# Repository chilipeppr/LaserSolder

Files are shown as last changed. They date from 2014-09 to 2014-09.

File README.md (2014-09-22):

LaserSolder
===========

The laser solderer widget for ChiliPeppr that uses an Arduino to control a laser with an infrared heat sensor and a PID to ensure accurate soldering.

ChiliPeppr Widget
-----------
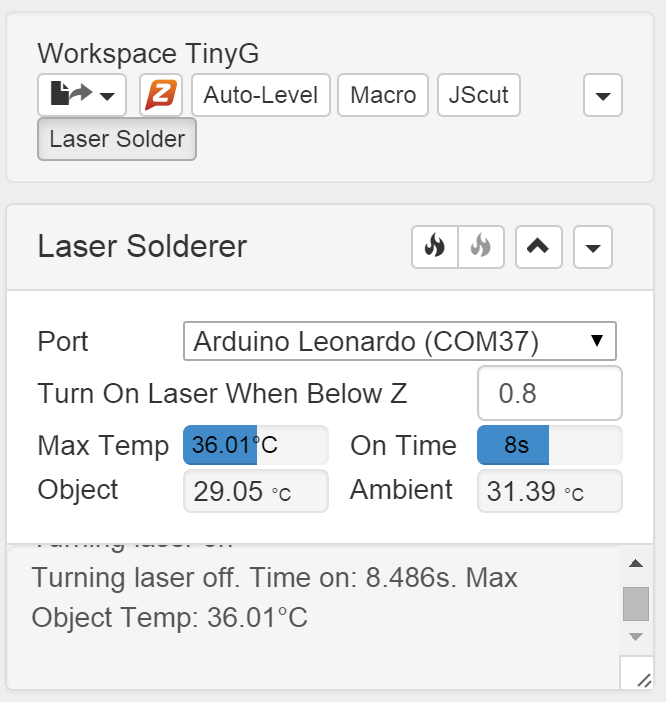
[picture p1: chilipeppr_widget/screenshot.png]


The widget lets you set at which Z height the laser will turn on. The laser is toggled from a normal Arduino. The command "laser-on" or "laser-off" is sent to the Arduino to toggle. You must also pick which port the Arduino is on. The Arduino also reports back every 500ms what the temperature of the Melexis infrared heat sensor readings are as a JSON string in the format {"a":27.54, "o":31.34} where "a" is the ambient temperature and "o" is the object's temperature in degrees Celsius. You can also toggle the laser manually.

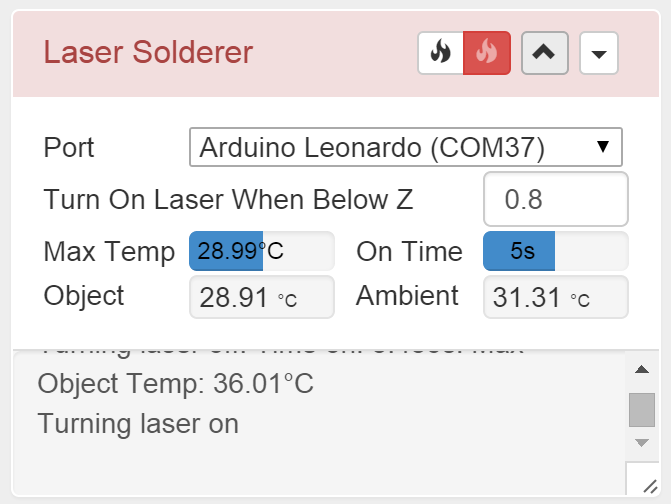
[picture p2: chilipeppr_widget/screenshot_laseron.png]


When the laser is on the widget goes red to indicate the state. You can always manually turn the laser off to override the auto-toggling based on the Z axis position.

Arduino Code
----------
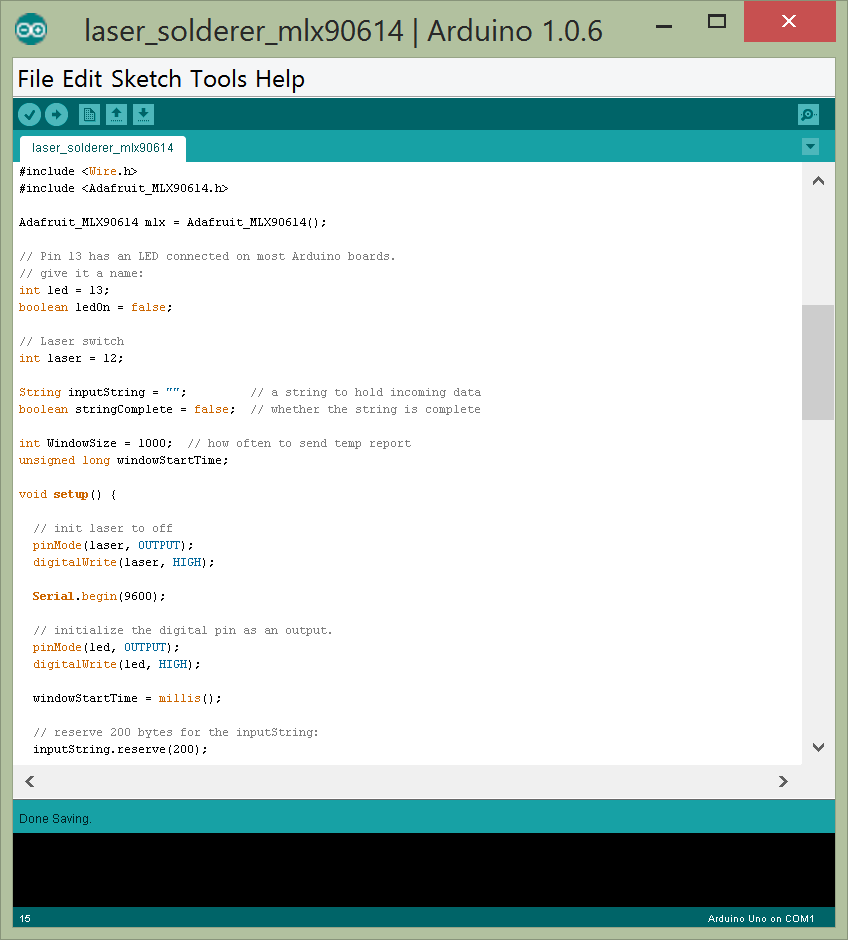
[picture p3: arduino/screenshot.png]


Just use a standard Arduino and upload the code contained in this repository. Modify as you like. You'll be running your Arduino on the same computer as your CNC machine so you can bind to both the serial port of your CNC controller like a TinyG as well as bind to your Arduino via its serial port.

The Arduino controls a laser by toggling PIN 12 on and off. You need
to connect a solid state relay, regular relay, or toggle a TTL signal
on a bench power supply. Or you can use something like a FlexMod P3
to toggle the laser on/off.

The laser used is a 3W 445nm Blue Diode laser in a standard 9mm casing
with a heatsink. You can find the laser at https://sites.google.com/site/dtrlpf/home/diodes/9mm-445nm

The Melexis MLX90614 is used for infrared temperature sensing. You
should get the 5 degree FOV version which is around $48. The link to this sensor is http://www.digikey.com/product-detail/en/MLX90614ESF-BCI-000-TU/MLX90614ESF-BCI-000-TU-ND/2666249

Eagle Schematics
----------
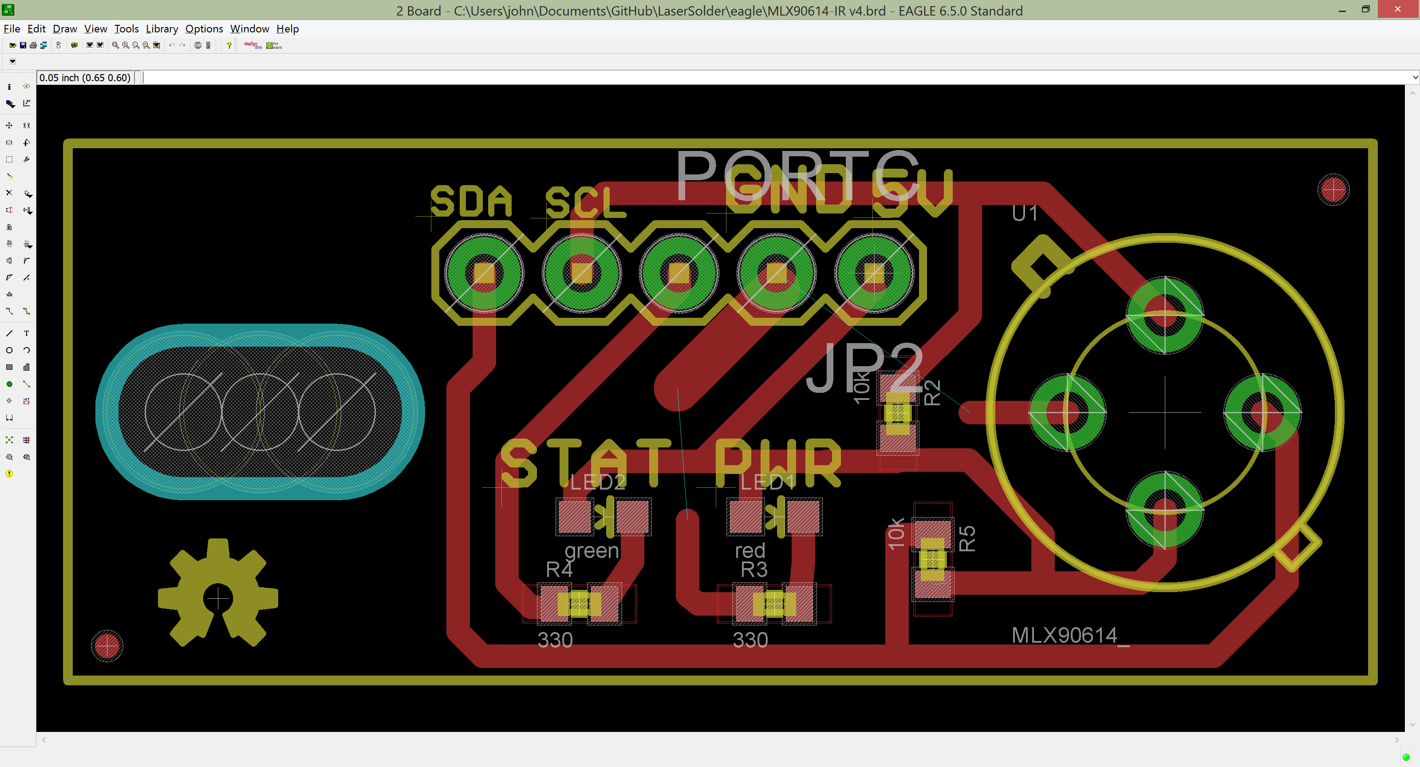
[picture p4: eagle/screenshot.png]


The Eagle design is in the eagle folder of this repository. It's simply a breakout board for the Melexis MLX90614 so you can connect it to your Arduino. It has two LEDs to indicate laser on/off status and power to the Melexis. There is a cutout on the board so you can bolt it to the design of the holder that is described below.

Freecad Design
----------
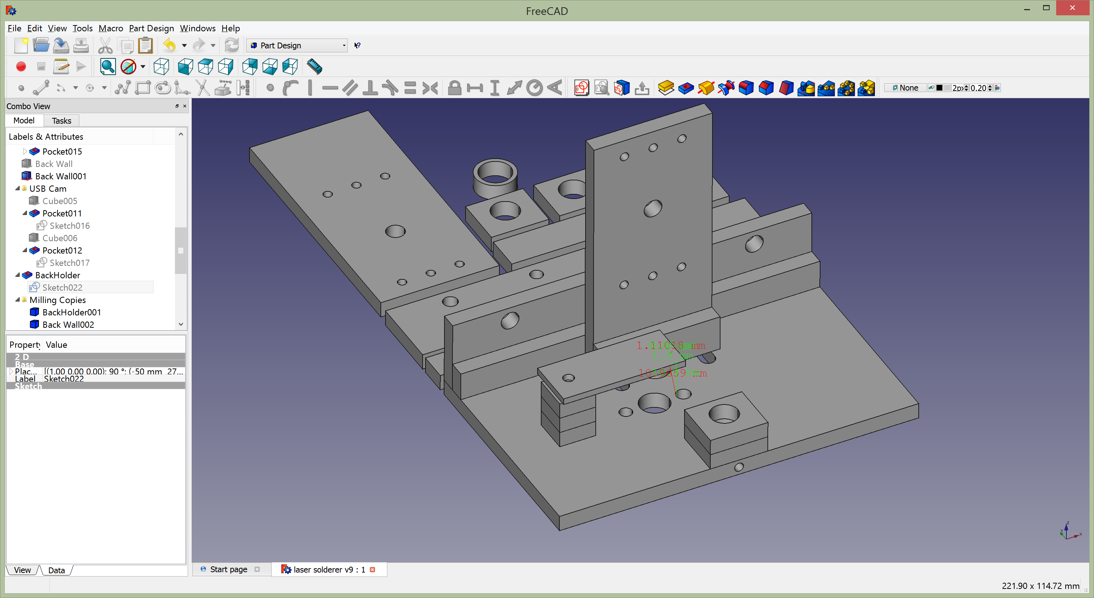
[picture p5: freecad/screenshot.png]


The design of the holder for the laser, Melexis MLX90614, the breakout board, and USB Microscope is in the freecad folder in this repo. Freecad is a great tool for basic CAD design. The CAD design was exported to DXF's and then brought into CamBam to generate the acrylic milling operations. The acrylic was then super glued or bolted together. Several M3 an M4 taps were created in the acrylic to enable bolting.

The back holder mounts to the standard Shapeoko mounts for a spindle so you can adjust the height of the laser holder on your Shapeoko.

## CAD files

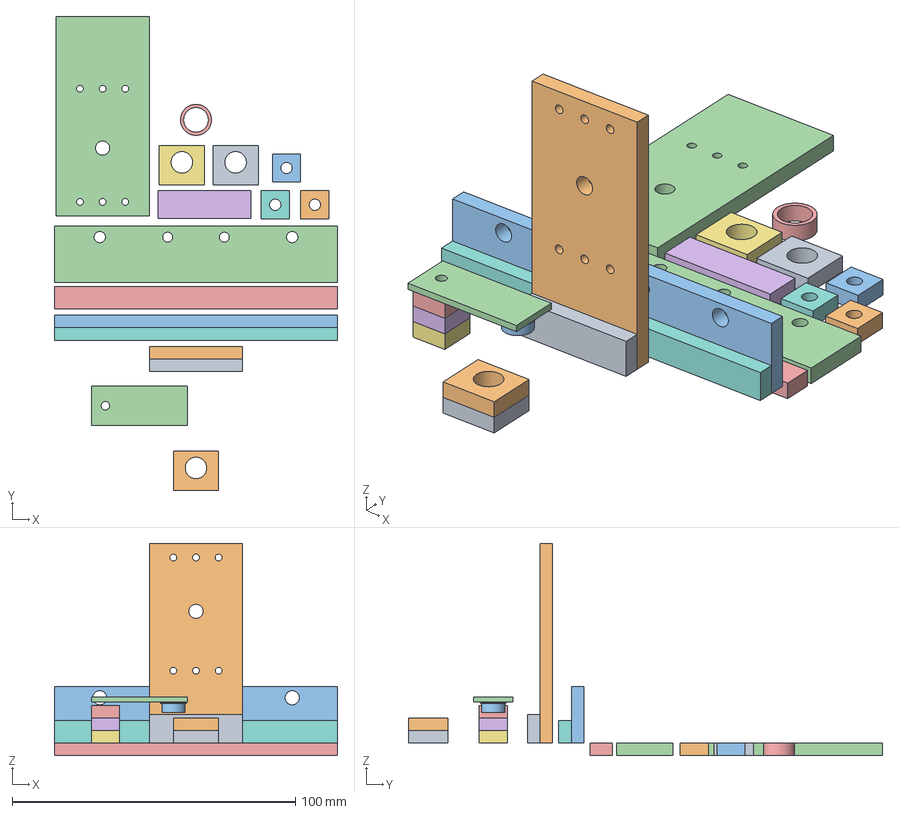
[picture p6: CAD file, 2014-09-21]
freecad/laser solderer v9.FCStd
100.0 x 167.6 x 75.0 mm
Laser Support001
CircuitBoardShimTop
CircuitBoardShimMiddle
Back Wall001
BackHolder
BackHolder001
Back Wall002
Laser Support002
USBCamShim
CircuitBoardShimMiddle001
USBCamShim001
CircuitBoardShimMiddle002
CircuitBoardShimMiddle003

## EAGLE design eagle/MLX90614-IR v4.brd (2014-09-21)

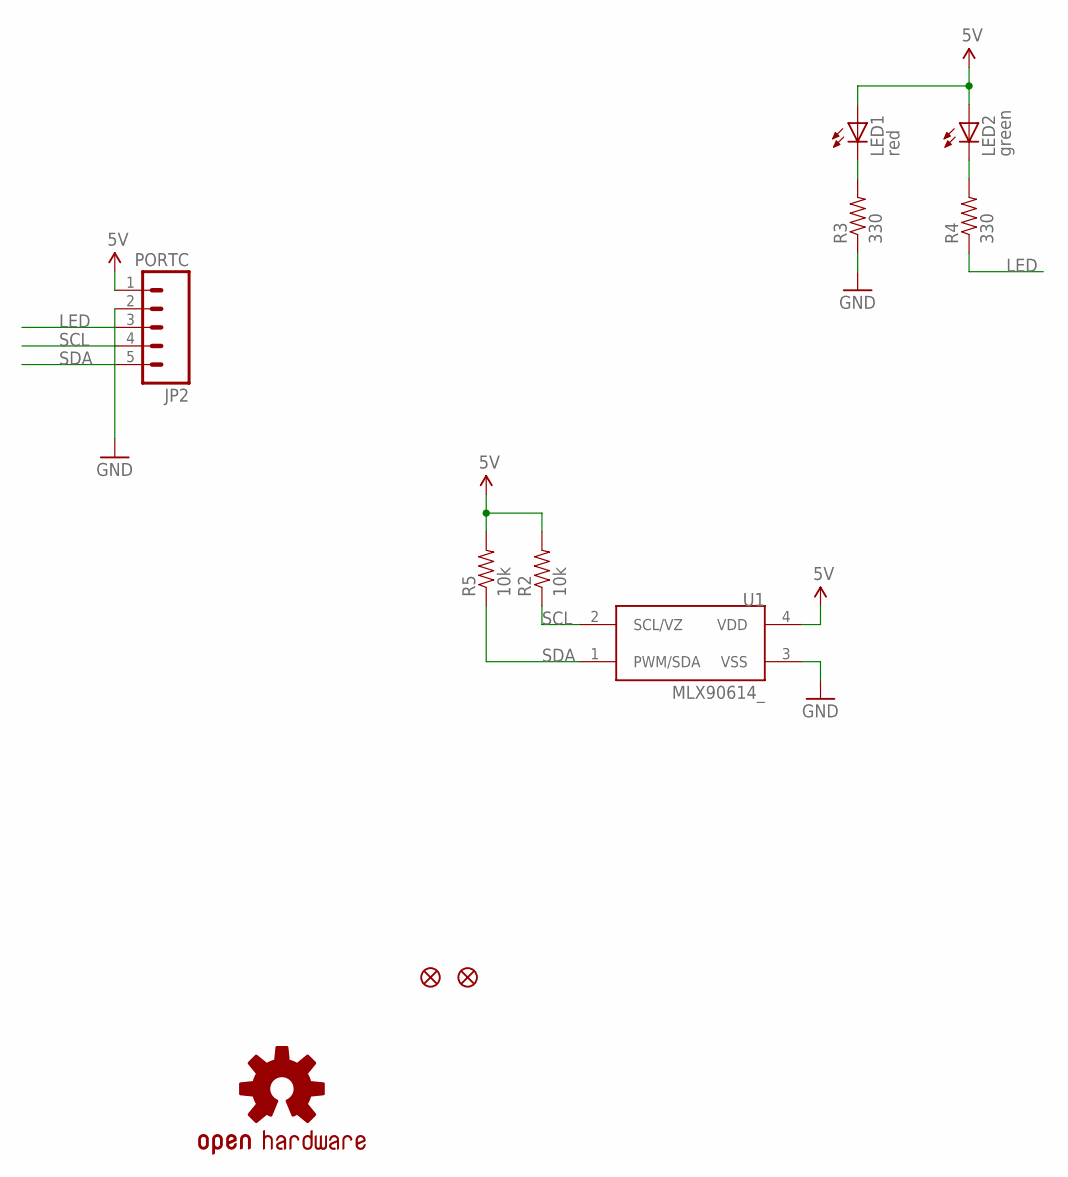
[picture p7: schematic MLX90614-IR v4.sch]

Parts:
JP2: PORTC; 1X05
JP3, JP5: FIDUCIAL1X2.5; FIDUCIAL-1X2.5
LED1: red; LED-0603
LED2: green; LED-0603
R2, R5: 10k; 0402-RES
R3, R4: 330; 0402-RES
U1: MLX90614_; TO-39
U$1: OSHW-LOGOS; OSHW-LOGO-S

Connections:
5V: JP2.1, LED1.A, LED2.A, R2.2, R5.2, U1.4 (VDD)
GND: JP2.2, R3.1, U1.3 (VSS)
LED: JP2.3, R4.1
unnamed: LED1.C, R3.2
unnamed: LED2.C, R4.2
SCL: JP2.4, R2.1, U1.2 (SCL/VZ)
SDA: JP2.5, R5.1, U1.1 (PWM/SDA)

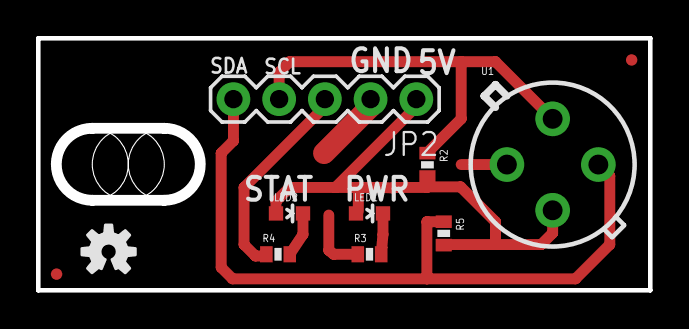
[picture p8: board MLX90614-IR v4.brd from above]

Board: 2 copper layers, 34.0 x 14.0 mm, 11 parts (0 on the bottom side), 7 nets.

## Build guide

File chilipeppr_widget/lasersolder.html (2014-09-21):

Laser Solderer

Port

Turn On Laser When Below Z

Max Temp

Unknown

On Time

Unknown

Object

0.00 °C

Ambient

0.00 °C

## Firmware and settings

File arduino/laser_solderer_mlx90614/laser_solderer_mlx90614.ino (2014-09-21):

/*
ChiliPeppr Laser Solderer Arduino Code

This file controls a laser by toggling PIN 12 on and off. You need
to connect a solid state relay, regular relay, or toggle a TTL signal
on a bench power supply. Or you can use something like a FlexMod P3
to toggle the laser on/off.

The laser used is a 452nm Blue Diode laser in a standard 9mm casing
with a heatsink.

The Melexis MLX90614 is used for infrared temperature sensing. You
should get the 5 degree FOV version which is around $35.
*/

/*************************************************** 
  This is a library example for the MLX90614 Temp Sensor

  Designed specifically to work with the MLX90614 sensors in the
  adafruit shop
  ----> https://www.adafruit.com/products/1748
  ----> https://www.adafruit.com/products/1749

  These sensors use I2C to communicate, 2 pins are required to  
  interface
  Adafruit invests time and resources providing this open source code, 
  please support Adafruit and open-source hardware by purchasing 
  products from Adafruit!

  Written by Limor Fried/Ladyada for Adafruit Industries.  
  BSD license, all text above must be included in any redistribution
 ****************************************************/

#include <Wire.h>
#include <Adafruit_MLX90614.h>

Adafruit_MLX90614 mlx = Adafruit_MLX90614();

// Pin 13 has an LED connected on most Arduino boards.
// give it a name:
int led = 13;
boolean ledOn = false;

// Laser switch
int laser = 12;

String inputString = "";         // a string to hold incoming data
boolean stringComplete = false;  // whether the string is complete

int WindowSize = 1000;  // how often to send temp report
unsigned long windowStartTime;

void setup() {
  
  // init laser to off
  pinMode(laser, OUTPUT);
  digitalWrite(laser, HIGH);
  
  Serial.begin(9600);

  // initialize the digital pin as an output.
  pinMode(led, OUTPUT);     
  digitalWrite(led, HIGH);
  
  windowStartTime = millis();
  
  // reserve 200 bytes for the inputString:
  inputString.reserve(200);
  
  // leonardo
  while (!Serial) {
    ; // wait for serial port to connect. Needed for Leonardo only
  }
  
  mlx.begin();  
  
  Serial.println("ChiliPeppr Laser Solderer MLX90614");  

}

void loop() {
  
  // print the string when a newline arrives:
  if (stringComplete) {
    //Serial.println(inputString); 
    
    if (inputString == "laser-on") {
      laserOn();
    } else if (inputString == "laser-off") {
      laserOff();
    } else if (inputString == "?") {
      Serial.println("ChiliPeppr Laser Control via Arduino");
      Serial.println("Commands:");
      Serial.println("laser-on\tTurn Laser On");
      Serial.println("laser-off\tTurn Laser Off");
    } else {
      Serial.println("Did not understand command: " + inputString);
    }
    
    // clear the string:
    inputString = "";
    stringComplete = false;
  }
  
  if(Serial.available() > 0)
   serialEvent();
   
  //ledOn = !ledOn;
  //if (ledOn) digitalWrite(led, HIGH);
  //else digitalWrite(led, LOW);
  
  if (millis() - windowStartTime >= WindowSize) { 
    // send report
    
    // reset the windowStartTime
    windowStartTime += WindowSize;
    Serial.print("{\"a\":"); 
    Serial.print(mlx.readAmbientTempC()); 
    Serial.print(", \"o\":"); 
    Serial.print(mlx.readObjectTempC()); 
    Serial.println("}");
    //Serial.print("Ambient = "); Serial.print(mlx.readAmbientTempF()); 
    //Serial.print("*F\tObject = "); Serial.print(mlx.readObjectTempF()); Serial.println("*F");
  
    //Serial.println();
  }
  //delay(500);
}

void laserOn() {
  digitalWrite(led, LOW);   // turn the LED on (HIGH is the voltage level)
  digitalWrite(laser, LOW);
  Serial.println("Laser On");
}

void laserOff() {
  digitalWrite(led, HIGH);   // turn the LED on (HIGH is the voltage level)
  digitalWrite(laser, HIGH);
  Serial.println("Laser Off");
}

/*
  SerialEvent occurs whenever a new data comes in the
 hardware serial RX.  This routine is run between each
 time loop() runs, so using delay inside loop can delay
 response.  Multiple bytes of data may be available.
 */
void serialEvent() {
  while (Serial.available()) {
    // get the new byte:
    char inChar = (char)Serial.read(); 
    
    // if the incoming character is a newline, set a flag
    // so the main loop can do something about it:
    if (inChar == '\n') {
      stringComplete = true;
    } else {
      // add it to the inputString:
      inputString += inChar;
    }
  }
}

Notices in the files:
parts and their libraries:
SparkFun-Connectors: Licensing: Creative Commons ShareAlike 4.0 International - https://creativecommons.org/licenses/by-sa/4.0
